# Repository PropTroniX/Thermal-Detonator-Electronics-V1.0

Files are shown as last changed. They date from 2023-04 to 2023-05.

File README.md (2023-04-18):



------------

##### *Table of Contents*
- [Arduino Class-A Thermal Detonator](#arduino-class-a-thermal-detonator)
- [Video of the Prototype](#video-of-the-prototype)
- [Parts Required](#parts-required)
- [Software Required](#software-required)
- [Wiring Schematics](#wiring-schematics)
- [Programming Instructions](#programming-instructions)
- [3D Print STL Files](#3d-print-stl-files)
- [Licence](#licence)
- [Donation Button](#donation-button)

### Arduino Class-A Thermal Detonator

Arduino code and STL files for a Star Wars Class-A Thermal Detonator. 
This is a very basic build just to add some functionality to your Star Wars Thermal Detonator.
Easy to build with only minimal wiring required using cheap and readily available parts. 
The 3D STL files to print the Class-A Thermal Detonator to fit these electronics are included in the Download.

If you looking for for a more Screen Accurate Thermal Detonator with more Sounds check out my - [Thermal Detonator V2.10 Kit](https://proptronix.co.uk/prop-electronics/td-electronics-kit-v2-10 "Thermal Detonator V2 Kit")





### Video of the Prototype

Check out my Videos of a 3D Printed Prototype with the Electronics Installed

YouTube Video 1- [Thermal Detonator V1.0 - Painted](https://youtu.be/5c1n84lufXM "Thermal Detonator V1.0 3D Printed and Painted")
YouTube Video 2- [Thermal Detonator V1.0 - Unpainted](https://youtu.be/FotBfXejvT4 "Thermal Detonator V1.0 - Unpainted")
YouTube Video 3- [Thermal Detonator V1.0 - Quick Build Instructions](https://youtu.be/IPiBrLOkG4U "Thermal Detonator V1.0 - Quick Build Instructions")

###  Parts Required

1 x Set of 3D STLFiles  - For 3D Printing the Class-A Thermal Detonator (Included FREE in the Download)

1 x [Thermal Detonator V1.0 PCB](https://proptronix.co.uk/prop-components/thermal-detonator-electronics-v1-0/thermal-detonator-v1-0-pcb"Thermal Detonator V1.0 PCB") - PCB for Components

1 x [Seeeduino XIAO](https://proptronix.co.uk/prop-components/thermal-detonator-electronics-v1-0/seeeduino-xiao "Seeeduino XIAO") - 32bit 48MHz Microchip USB Type-C 

1 x [DFPlayer Mini MP3](https://proptronix.co.uk/prop-components/thermal-detonator-electronics-v1-0/dfplayer_mini_mp3 "DFPlayer Mini MP3]") - Mini MP3 Sound Player

1 x[PAM8403 Class-D Amplifier](https://proptronix.co.uk/prop-components/thermal-detonator-electronics-v1-0/pam8403-class-d-amplifier "PAM8403 Class-D Amplifier") - 2-channel, 3W, class-D Audio Amplifier

1 x [Micro SD-Card](https://proptronix.co.uk/prop-components/thermal-detonator-electronics-v1-0/4gb-micro-sd-card "Micro SD-Card") - Minimum 512K

1 x [Mini Limit Lever Switch](https://proptronix.co.uk/prop-components/thermal-detonator-electronics-v1-0/mini-limit-lever-switch "Mini Limit Lever Switch ") - Used on the Slide Switch to Turn On/Off

1 x [Ball Tilt Sensor SW-520D](https://proptronix.co.uk/prop-components/thermal-detonator-electronics-v1-0/ball-tilt-sensor-sw-520d "Ball Tilt Sensor SW-520D") - (Activation Switch for Thermal Explosion

1 x [28mm Low Profile Speaker](https://proptronix.co.uk/prop-components/thermal-detonator-electronics-v1-0/28mm-low-profile-speaker "28mm Low Profile Speaker") - (Thermal Detonator Speaker

1 x [5mm Red LED](https://proptronix.co.uk/prop-components/thermal-detonator-electronics-v1-0/5mm-water-clear-led "5mm Red LED") - Top LED - Power Indicator & LED Functions

1 x [5mm Red Flat Top LED Lens](https://proptronix.co.uk/prop-components/thermal-detonator-electronics-v1-0/5mm-red-led-lens-cover "5mm Red Flat Top LED Lens") - Top LED Power Indicator Cover

3 x [3mm LED](https://proptronix.co.uk/prop-components/thermal-detonator-electronics-v1-0/3mm-clear-leds "3mm LED") - Front 3 LED's - Can be any Colour but I use White or Yellow

7 x [JST PH-2.0 Male Lead](https://proptronix.co.uk/prop-components/thermal-detonator-electronics-v1-0/jst-ph-2-0-male-lead "JST PH-2.0 Male Lead") - Used to Connect the Components to the PCB

7 x [JST PH-2.0 Female Sockets](https://proptronix.co.uk/prop-components/thermal-detonator-electronics-v1-0/jst-ph-2-0-female-socket "JST PH-2.0 Female Sockets") - Used to Connect the JST PH-2.0 Leads to the PCB

1 x [Header Pin Set](https://proptronix.co.uk/prop-components/thermal-detonator-electronics-v1-0/td-pin-header-set-f "Header Pin Set") - Used to for Connecting the Seeeduino, DFPlayer & PAM8403 to the PCB

3 x [3mm Metal LED Holder/Bezel](https://proptronix.co.uk/prop-components/thermal-detonator-electronics-v1-0/led-holder-metal "3mm Metal LED Holder/Bezel") - Used for the Front LED's (Optional)

1 x [Slide Switch Screws](https://proptronix.co.uk/prop-components/thermal-detonator-electronics-v1-0/thermal-detonator-v1-0-screws "Slide Switch Screws") - Used to Secure the Top Slide Switch to the Top Dome

All parts listed above are available from my Online Shop , eBay, Amazon or AliExpress.

I also sell updated [Thermal Detonator V2.10 Electronics](https://proptronix.co.uk/prop-electronics/td-electronics-kit-v2-10 "Thermal Detonator V2.10 Electronics") as a Self Build Kit or Pre-Built in my Shop. Better Screen Accurate STL Design with more functions on the Electronics.

###  Software Required

You will need the following Software & Libraries to install and setup the Thermal Detonator Arduino Code on the Seeeduino XIAO.
- The latest version of Arduino IDE - [Download from the Arduino Site](https://www.arduino.cc/en/Main/Software "Download from the Arduino Site")

**Adding Seeduino XIAO to Arduino IDE :**

Click on File > Preference, and fill Additional Boards Manager URLs with the URL below:
https://files.seeedstudio.com/arduino/package_seeeduino_boards_index.json

**Arduino Libraries Needed:**

- SoftwareSerial - Included in the Download
- DFRobotDFPlayerMini - Included in the download

**TDTroniX V1.0 Arduino Thermal Detonator Code:**

- Arduino-Thermal-Detonator-V1.0.ino - Included in the Download

###  Wiring Schematics




###  Programming Instructions

1. Copy the Two Included Libraries (SoftwareSerial & DFRobotDFPlayerMini ) into your Arduino Libraries Folder.

2. Run the Arduino IDE Application

3. File Open and locate the Arduino-Thermal-Detonator-V1.0 Directory and open the Load the Arduino-Thermal-Detonator-V1.0.ino file.

4. Select Tools: Board: and select Seeeduino XIAO

5. Select Tools: Port: and Select the COM Port your Seeeduino XIAO board is plugged in to.

6. Select Tools: Programmer: and choose AVRISP mkII.

7. Upload the Thermal-Detonator-V1.0.ino code to the board

You should now have a functioning Thermal Detonator

### 3D Print STL Files
The download also includes a set of Thermal Detonator V1.0 3D Printable STL Files. These are adapted from the Free Files that are available from [Thingiverse](https://www.thingiverse.com/thing:809004 "Thingiverse") by Oubliette. I changed some of the design and added the Electronics Holder.



###  Licence

This work is licensed under the Creative Commons Attribution-NonCommercial-ShareAlike 4.0 International License.
To view a copy of this license, visit https://creativecommons.org/licenses/by-nc/4.0/

### Donation Button
 Please feel free to donate a cup of coffee if you find this code useful. Thank You

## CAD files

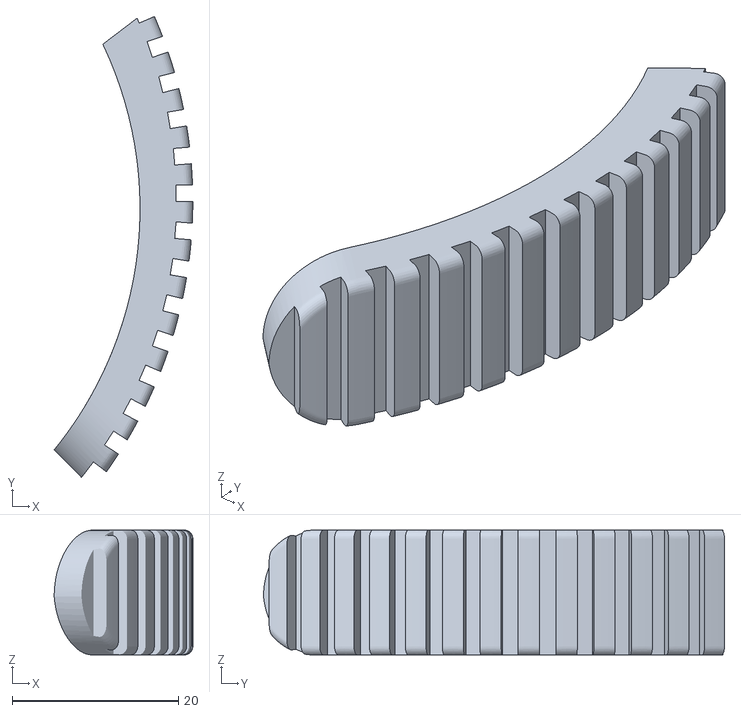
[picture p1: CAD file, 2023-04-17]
Thermal-Detonator-STL-Files/Part_#4_Slide_Switch_Tracks.stl
16.7 x 55.4 x 15.0

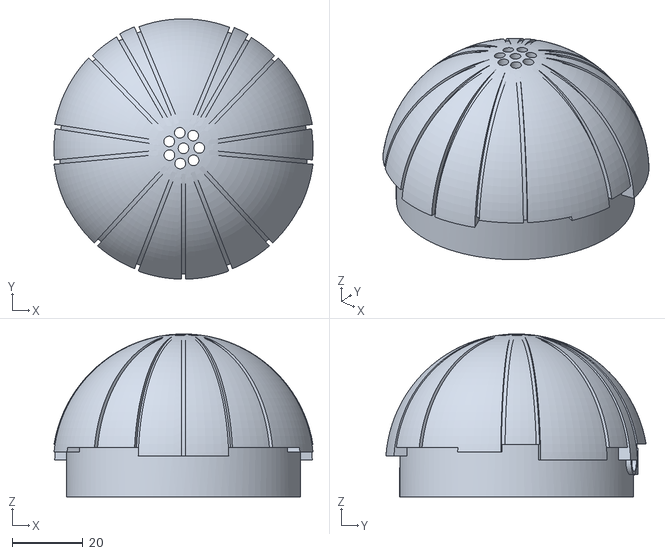
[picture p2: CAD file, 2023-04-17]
Thermal-Detonator-STL-Files/Part_#1_Dome_Bottom.stl
73.1 x 73.4 x 46.0

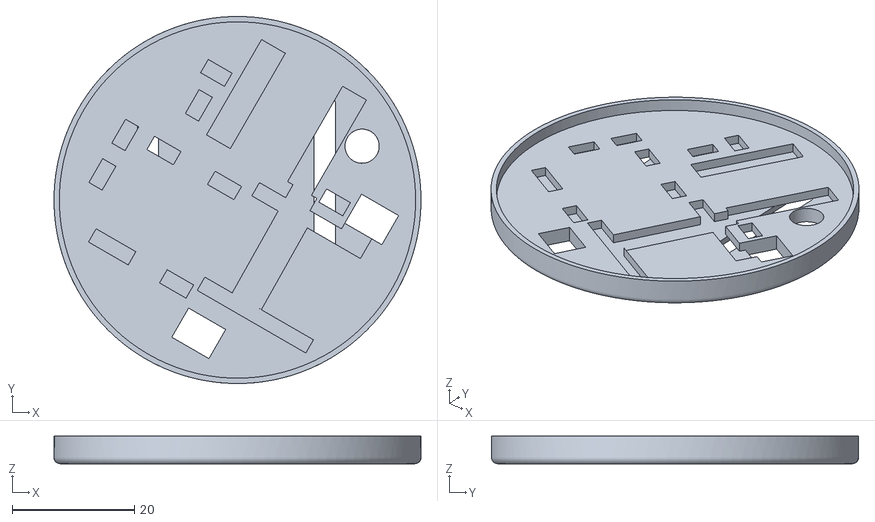
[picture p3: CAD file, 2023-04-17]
Thermal-Detonator-STL-Files/Part_#9_PCB_Holder.stl
60.0 x 60.0 x 4.50

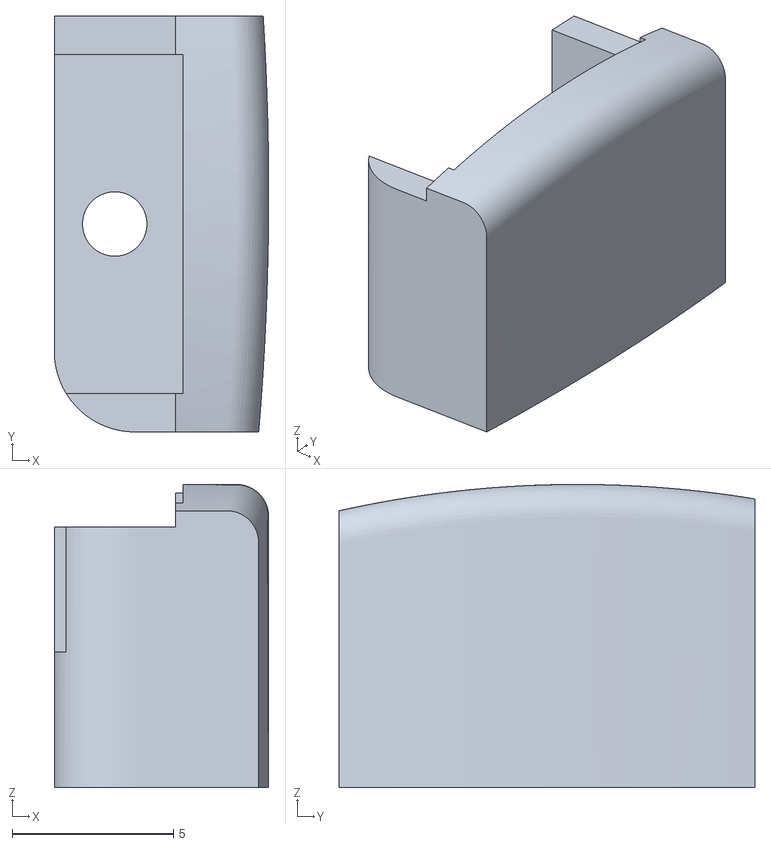
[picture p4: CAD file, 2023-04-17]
Thermal-Detonator-STL-Files/Part_#5_Slide_Switch_Retainer_RIGHT.stl
6.65 x 12.9 x 9.40

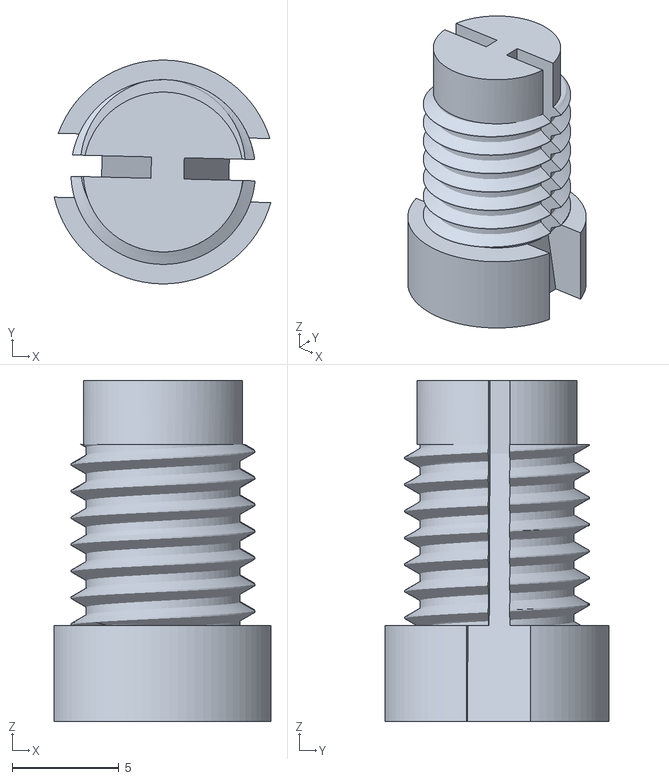
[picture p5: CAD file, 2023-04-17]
Thermal-Detonator-STL-Files/Part_#7_Top_LED_Holder.stl
10.2 x 10.5 x 16.0

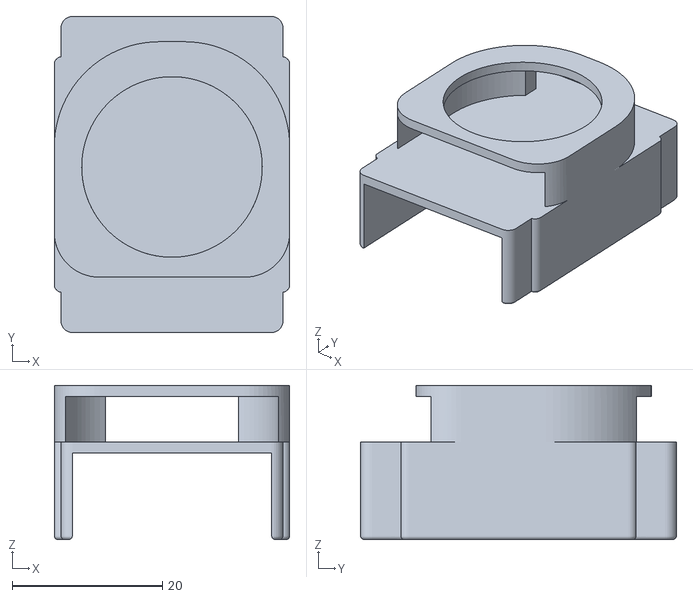
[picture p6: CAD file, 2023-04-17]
Thermal-Detonator-STL-Files/Part_#10_PCB_Battery_Speaker_Holder.stl
31.3 x 42.0 x 20.5

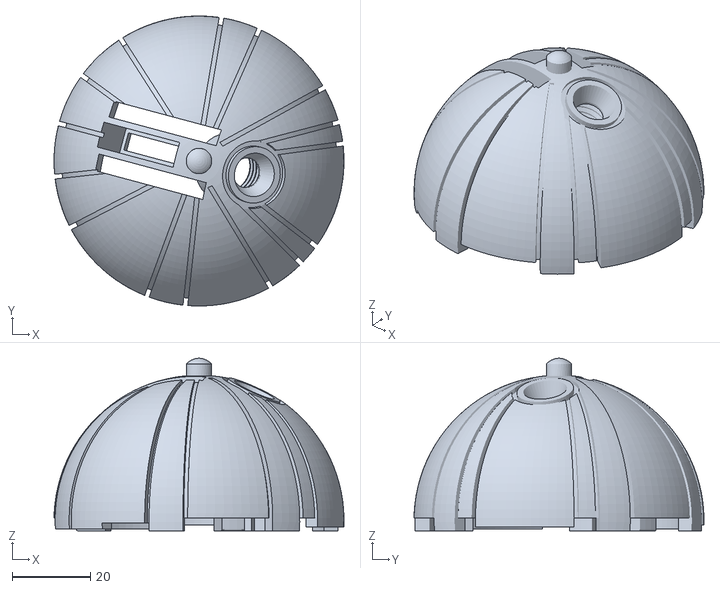
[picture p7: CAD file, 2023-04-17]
Thermal-Detonator-STL-Files/Part_#2_Dome_Top.stl
74.0 x 74.0 x 44.1

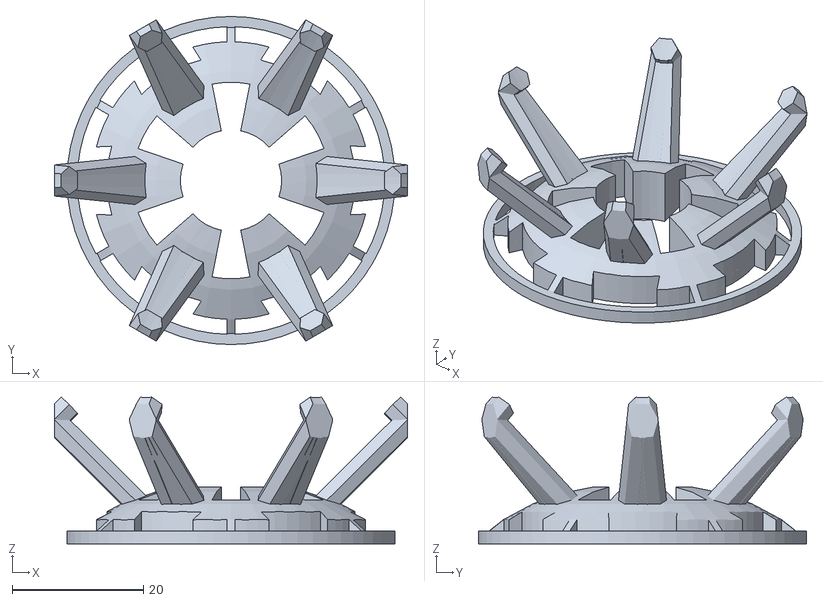
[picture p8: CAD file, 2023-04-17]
Thermal-Detonator-STL-Files/Part_#12_Stand_6_Arm.stl
53.8 x 50.0 x 22.4

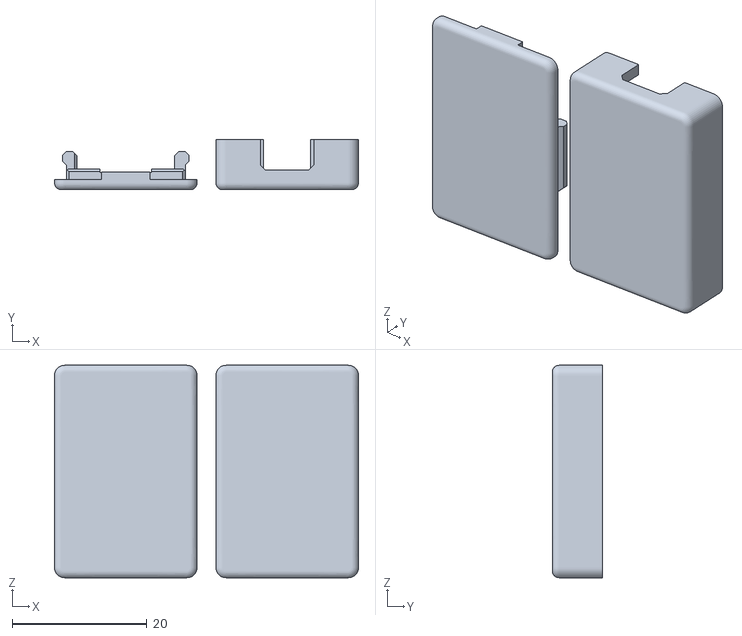
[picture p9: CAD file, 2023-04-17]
Thermal-Detonator-STL-Files/Part_#13_TP4056-Battery_Charger_Case.stl
45.2 x 7.50 x 31.6

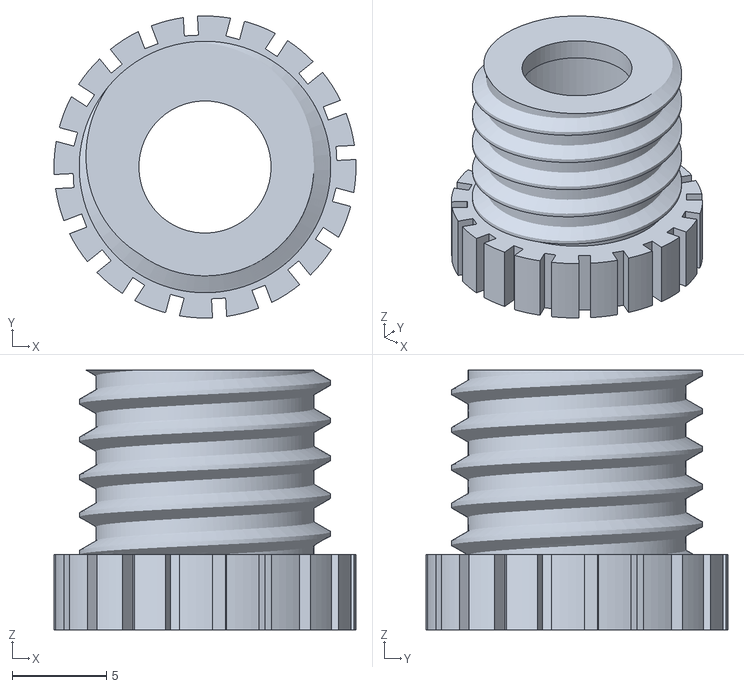
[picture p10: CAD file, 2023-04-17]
Thermal-Detonator-STL-Files/Part_#8_Top_LED_Mount.stl
16.0 x 16.0 x 13.8

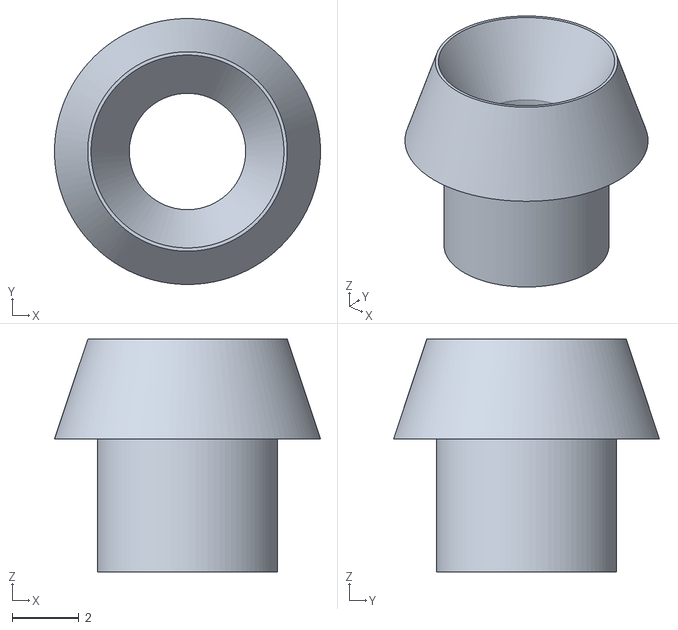
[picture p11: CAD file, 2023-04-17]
Thermal-Detonator-STL-Files/Part_#14_Front_LED_Bezel_X3.stl
8.00 x 8.00 x 7.00

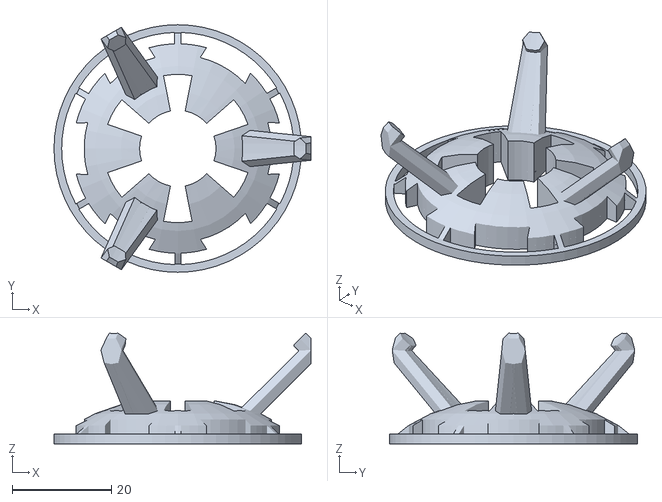
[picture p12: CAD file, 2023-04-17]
Thermal-Detonator-STL-Files/Part_#11_Stand_3_Arm.stl
51.9 x 50.0 x 22.4

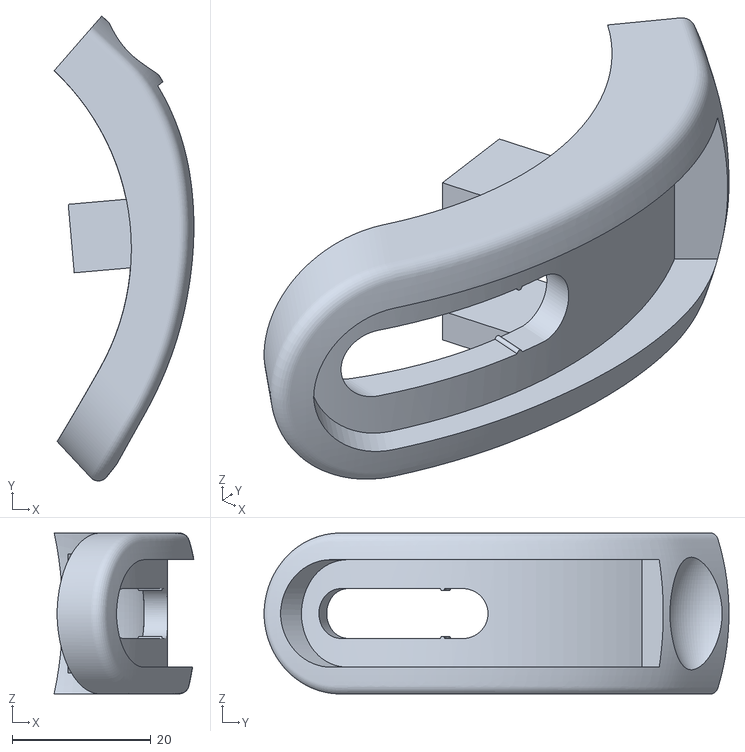
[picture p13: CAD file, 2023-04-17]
Thermal-Detonator-STL-Files/Part_#3_Slide_Switch.stl
20.2 x 67.0 x 23.2

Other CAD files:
Thermal-Detonator-STL-Files/Part_#6_Slide_Switch_Retainer_LEFT.stl

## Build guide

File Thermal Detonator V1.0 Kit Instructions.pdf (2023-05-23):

# Thermal Detonator V1.0

# TDTroniX Electronics Kit Build Instructions

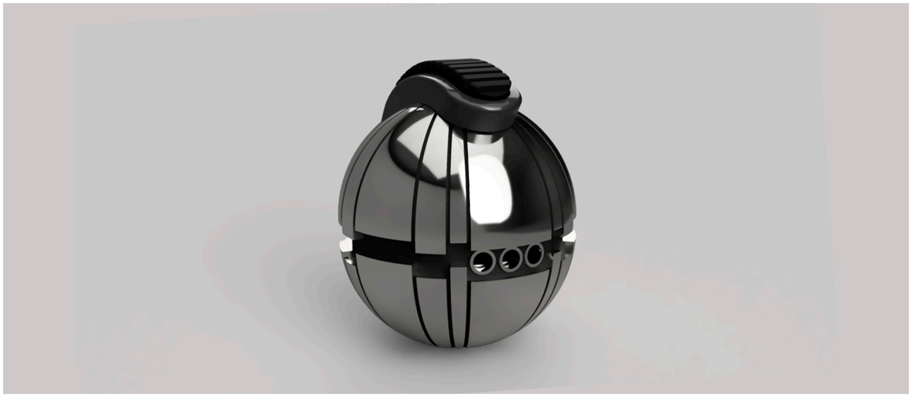
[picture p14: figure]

3D Printed Thermal Detonator V1 Model Kit
Congratulations on getting the STL Files for the 3D printed plastic model of a Class-A Thermal Detonator
All parts can be 3D printed in either PLA or ABS plastic. Pictures featured in the instructions are the actual STL files.

It is recommended you use PPE (Personal Protection Equipment) when construction this model kit. Sanding any plastic creates a fine dust which if breathed into the lungs, is not good. The dust can also get in to your eyes, so please use both a mask and goggles when sanding parts and always work in a well ventilated area. Plastic dust can get everywhere!

Tools List

The following tools are what I recommended to use to build your Thermal Detonator.

- Eye Protection - Goggles to protect your eye’s from the dust particles
- Dust Mask - For protection from breathing in the dust particles
- Sandpaper - Various grades 80 Grit, 180 Grit and Wet & Dry 600 Grit (A few sheets of each)
- Small Metal Files - Various widths and shapes
- Super Glue
- 2 Part Epoxy Glue
- Small Pair of Side Cutters
- Needle Nose Pliers
- Exacto Knife
- Filler - Bondo, wood filler, fine car filler or any other type of filler that is easy to sand can be used.
- Paint - Filler Primer, Colours of your choice

3D Printed Parts List

PART #1: Dome Bottom | PART #5: Switch Retainer Right | PART #9: PCB Holder | PART #13: Battery Charger Case
PART #2: Dome Top | PART #6: Switch Retainer Left | PART #10: Battery/Speaker Holder | PART #14: Front LED Bezel X 3
PART #3: Slide Switch | PART #7: LED Holder | PART #11: 3 Arm Stand Panel
PART #4: Slide Switch Tracks | PART #8: LED Mount | PART #12: 6 Arm Stand

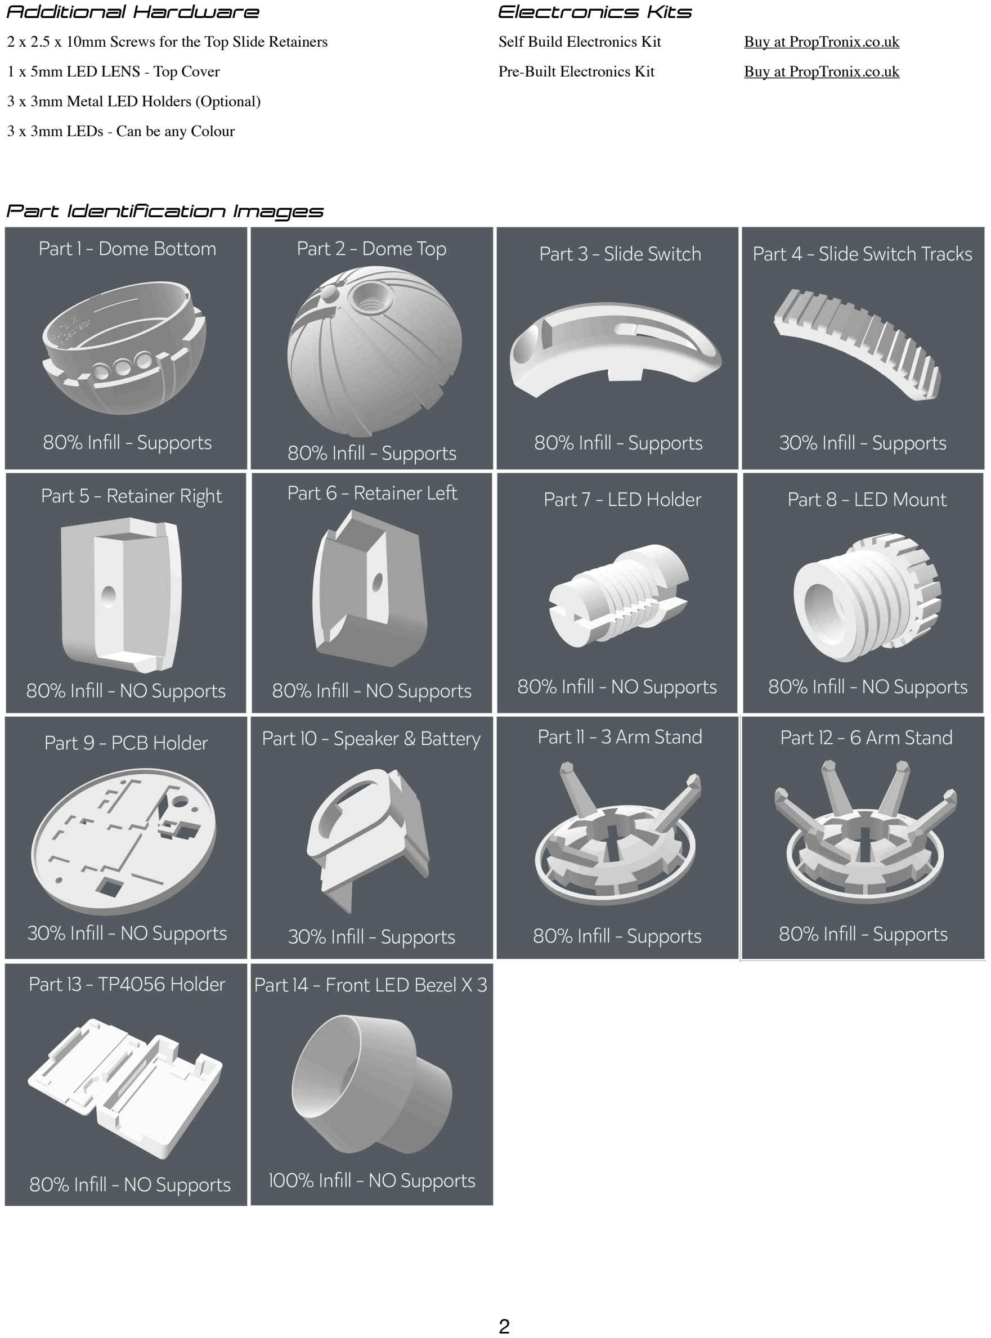
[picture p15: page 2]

Additional Hardware | Electronics Kits
2 x 2.5 x 10mm Screws for the Top Slide Retainers | Self Build Electronics Kit | Buy at PropTronix.co.uk (http://proptronix.co.uk/prop-electronics/thermal-detonator-electronics-kit-v1-0)
1 x 5mm LED LENS - Top Cover | Pre-Built Electronics Kit | Buy at PropTronix.co.uk (http://proptronix.co.uk/prop-electronics/thermal-detonator-electronics-kit-v1-0)

3 x 3mm Metal LED Holders (Optional)

3 x 3mm LEDs - Can be any Colour

Part Identification Images

Sanding and Filling

Sanding all the parts is a necessary process and the more time you take on this process the better the finish of your Thermal Detonator will be. Start with the 80 grit sandpaper and reduce the grit until a nice smooth finish is achieved.

PLEASE WEAR A DUST MASK & GOGGLES WHEN SANDING

DO NOT USE POWER TOOLS for sanding, these create heat very quickly and will soften the plastic and potentially ruin the part. Hand sanding is a much slower process but with patience and time you will achieve a really good finish ready for assembling and painting.

- Rounded Parts - Roll sandpaper around the part to sand, both inside and outside of barrels can be sanded this way.
- Flat Surfaces - Use a sheet of sandpaper on a flat surface to sand these parts.
- Awkward Shapes and Small Details - Use small metal files with shaped sides and sanding sticks to sand these parts, being careful not to sand away the details too much.

Check all parts for voids and gaps and fill with filler, once dry and hardened sand these parts again. ONLY move on to assembling the Thermal Detonator once you are really happy with the sanded finish of all the parts.

Painting

The main colours used for painting the Thermal Detonator are Black and Silver, but you can paint it in whatever colours you choose. I recommend using cans of acrylic spray paints, but you can also use an airbrush.

PLEASE WEAR A MASK WHEN PAINTING

- Always paint in a well ventilated area, preferably outside.
- Wear PPE (Personal Protective Equipment) when painting.
- Hang parts for printing where possible - This gives a better angle for painting and also for drying the parts.
- Apply serval lights coats of paint rather than one which coat and try to avoid drips and runs.
1. Filler Primer - Spray Paint all parts with Filler Primer - This will fill any very small voids or gaps. If there are still some voids and gaps fill these with filler and sand all the parts with very fine grit wet and dry sandpaper to achieve a real good smooth finish ready for the final colour.
2. Main Colour - Use several lights coats of paint allowing each to dry for the recommended time before applying the next coat. Don’t rush and try to paint thick coats of paint, you will possibly loose some of the finer details on the parts, and possibly have to start the sanding process again.
3. Allow the paint to fully dry before attempting to assemble the Thermal Detonator. I recommend at least 24 hours.
4. Remember any parts that are required to be glued together will need to have the paint paint sanded first. Gluing Painted parts together is NOT recommended.
5. Weathering - This is a personal choice. If you want to give your Thermal Detonator the weathered look check out the many video’s on YouTube showing how to achieve that weather look.

Assembling the 3D Printed Thermal Detonator V1.0

### 1. Top LED Assembly

Put the 5mm Red LED Lens on top of Part #7 - Top LED Holder and screw into Part #8 - Top LED Mount then screw into the Part #2 - Dome Top.

### 2. Front LED Assembly

Fix the 3 x 3mm Metal LED Holders (Optional) or use Part #14 - Front LED Bezel into the front of Part #1 - Dome Bottom and insert 3 x 3mm LEDs.

### 3. Switch Assembly

Glue Part #4 - Slide Switch Tracks into Part #3 - Slide Switch then place into Part #2 - Dome Top making sure the curved end faces forward.
Put Part #5 - Retainer Right & Part #6 - Retainer Left on to the lugs of Part #3 - Slide Switch and use the 2 x M2.5 x 10mm Screws to fix. Make sure these are not done up too tightly or the switch wont slide.

### 4. Thermal Detonator Assembly

Place Part #1 - Dome Top onto Part #2 - Dome Bottom aligning the Part #1 - Dome Top tabs into the Holes on Part #2 - Dome Bottom and turn clockwise until aligned so secure.
You should now have a completed Class-A Thermal Detonator

Fitting TDTroniX Electronics into the Thermal Detonator

Pre-Built Kit
Click the link to watch the Pe-Built Kit Quick install Video - TDTroniX Pre-Built Kit Installation (https://www.youtube.com/watch?v=IPiBrLOkG4U)

Self Build Kit
1. Solder the Seeeduino XIAO, PAM8403 Amplifier & DFPlayer Mini Female Pin Headers to the TDTroniX PCB.
2. Solder the Male Header Pins to the Seeeduino XIAO and PAM8403 Amplifier.
3. Place the Seeeduino XIAO, DFPlayer Mini and PAM8403 Amplifier into the Soldered Pin Headers on the PCB.
3. Solder the JST PH 2.0 Female Connector Sockets to the PCB - RED - Top LED, YELLOW - Front LED’s, BLUE - Lever Switch - GREEN - Speaker, BLACK - Battery
4. Solder the GREEN JST PH 2.0 Make Lead to the Speaker - Red Lead to Speaker POS and Black Lead to Speaker NEG
5. Solder the BLUE JST PH 2.0 Male Lead to the two outside connectors on the Micro Lever Switch - It does NOT matter which way round the leads go.
6. Solder the RED JST PH 2.0 Male Lead to the Top 5mm Red LED - Red Lead to LED POS and Black Lead to led NEG
7. Solder the 3 YELLOW JST PH 2.0 Male Leads to the 3 Front 3mm LED’s - Red Lead to LED POS and Black Lead to LED NEG
8. Change the Male connector on your Battery to the BLACK JST PH 2.0 Male Lead - Red Lead to Battery POS and Black Lead to Battery NEG

LED Resistors and switch resistor are NOT required as these are pre-soldered on the TDTroniX PCB.

9. One all leads and sockets are soldered in place follow the - TDTroniX Pre-Built Kit Installation (https://www.youtube.com/watch?v=IPiBrLOkG4U) video.

Congratulations! you should now have a fully working Class-A Thermal Detonator.

Website: www.proptronix.co.uk

Email: info@proptronix.co.uk

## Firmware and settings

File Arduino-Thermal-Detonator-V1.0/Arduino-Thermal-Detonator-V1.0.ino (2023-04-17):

/*
   Thermal Detonator V1.0

   Released on: 21st June 2019
   Author:    PropTroniX (info@proptronix.co.uk)
   Source :   https://github.com/PropTroniX/Thermal-Detonator-V1.0
   Description: Light and Sound for a 3D Printed Class-A Thermal Detonator

   Electronics Parts Available at www.proptronix.co.uk
   Thermal Detonator V1.0 STL Files are Included FREE in the GitHub.
   
   This work is licensed under the Creative Commons Attribution-NonCommercial-ShareAlike 4.0 International License.
   To view a copy of this license, visit http://creativecommons.org/licenses/by-nc-sa/4.0/.

*/

#include "SoftwareSerial.h"
#include "DFRobotDFPlayerMini.h"

SoftwareSerial mySoftwareSerial(7, 6); // RX, TX
DFRobotDFPlayerMini myDFPlayer;
void printDetail(uint8_t type, int value);

enum {NORMAL, SPECIAL} currentState = NORMAL;

//suffix N for Normal
byte led1StateN [] = {1, 1, 1, 1, 0, 0, 0, 1, 0};
byte led2StateN [] = {1, 0, 1, 0, 1, 1, 0, 1, 0};
byte led3StateN [] = {1, 0, 0, 1, 1, 0, 1, 0, 0};

//suffix S for Special
byte led1StateS [] = {1, 1, 1, 1, 1, 1, 1, 1, 0};
byte led2StateS [] = {1, 0, 1, 0, 1, 0, 0, 1, 0};
byte led3StateS [] = {1, 0, 0, 0, 0, 0, 1, 0, 0};

byte ledPin1 = 3;
byte ledPin2 = 4;
byte ledPin3 = 5;

int ledPinON = 2;
int triggerPin = 8;

int buttonState = 0;

unsigned long currentMillis;
unsigned long previousMillisPulse = 0;
int pulseInterval = 500;
bool pulseState = LOW;
unsigned long previousMillisBlink = 0;
int blinkInterval = 1000;

byte arrayPos = 0;
int passNumber = 1;

byte specialButtonPin = 14;

void setup()
{

  pinMode(triggerPin, INPUT);
  pinMode(ledPinON, OUTPUT);
  pinMode(ledPin1, OUTPUT);
  pinMode(ledPin2, OUTPUT);
  pinMode(ledPin3, OUTPUT);
  digitalWrite(ledPin1, LOW);
  digitalWrite(ledPin2, LOW);
  digitalWrite(ledPin2, LOW);
  pinMode(specialButtonPin, INPUT_PULLUP);


  mySoftwareSerial.begin(9600);
  Serial.begin(115200);

  if (!myDFPlayer.begin(mySoftwareSerial)) {  //Use softwareSerial to communicate with mp3.
    while(true){
    }
  }
  
  myDFPlayer.volume(25);  //Set volume value. From 0 to 30


  myDFPlayer.play (3);
  delay (1500);

  myDFPlayer.play (2);
  delay (300);

}//setup

void loop()
{

  digitalWrite(ledPinON, HIGH);

  buttonState = digitalRead(triggerPin);

  if (buttonState == HIGH) {

    bomb ();

  } else {

    lights ();

  }
}


void lights()
{

  currentMillis = millis();
  doPulse();
  doStates();

}//lights

void doPulse()
{
  if (currentMillis - previousMillisPulse >= pulseInterval)
  {
    pulseState = !pulseState;
    digitalWrite(LED_BUILTIN, pulseState);
    previousMillisPulse = currentMillis;


  }
}

void doStates()
{

  switch (currentState)
  {
    case NORMAL:

      if (currentMillis - previousMillisBlink >= blinkInterval)
      {
        passNumber++;
        digitalWrite(ledPin1, led1StateN [arrayPos]);
        digitalWrite(ledPin2, led2StateN [arrayPos]);
        digitalWrite(ledPin3, led3StateN [arrayPos]);
        arrayPos++;
        if (arrayPos > 8)
        {
          arrayPos = 0;
        }
        previousMillisBlink = currentMillis;
      }

      if (!digitalRead(specialButtonPin))
      {
        currentState = SPECIAL;
        arrayPos = 0;
        previousMillisBlink = currentMillis;
      }

      break;

    case SPECIAL:

      if (currentMillis - previousMillisBlink >= blinkInterval)
      {
        passNumber++;
        digitalWrite(ledPin1, led1StateS [arrayPos]);
        digitalWrite(ledPin2, led2StateS [arrayPos]);
        digitalWrite(ledPin3, led3StateS [arrayPos]);
        arrayPos++;

        previousMillisBlink = currentMillis;
      }

      if (arrayPos > 8)
      {
        currentState = NORMAL;
        arrayPos = 0;
//        Serial.println(" ******* Going to NORMAL ********");
      }

      break;

  }//switch
}//doStates

void bomb ()  {

  myDFPlayer.play (1);
  delay (300);

  for (int counter = 1; counter <= 40; counter = counter + 1) {
    digitalWrite(ledPin1, HIGH);
    digitalWrite(ledPin2, HIGH);
    digitalWrite(ledPin3, HIGH);
    digitalWrite(ledPinON, LOW);
    delay(100);
    digitalWrite(ledPin1, LOW);
    digitalWrite(ledPin2, LOW);
    digitalWrite(ledPin3, LOW);
    digitalWrite(ledPinON, HIGH);
    delay(100);

  }
}
